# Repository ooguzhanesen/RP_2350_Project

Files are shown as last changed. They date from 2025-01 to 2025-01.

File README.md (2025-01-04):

# RP2350 PALS OKUMA VE GONERME KARTI
## KART ÖZELLİKLERİ 
- RP2350 mikrodenetleyici
- MG2608 GSM Modülü
- Ds3231 RTC
- RS485
- 2 adet optoizalatörlü Pals okuma girişi
- Adc okuma girişi
- Type c girişi
- 7-28 to 5v voltaj girişi
- 5v multiplexer 

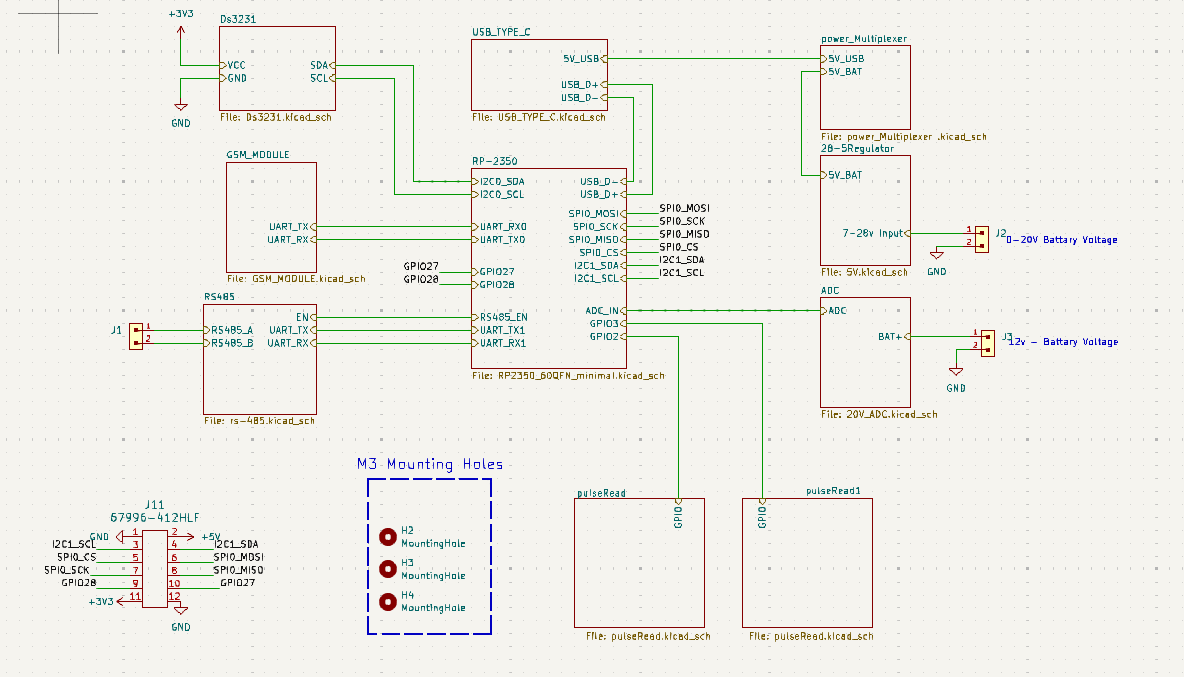
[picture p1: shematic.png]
proje şematik


## PCB TASARIMI
PCB kiCad üzerinden 4 kartlı olacak şekilde tasarlanmıştır. 
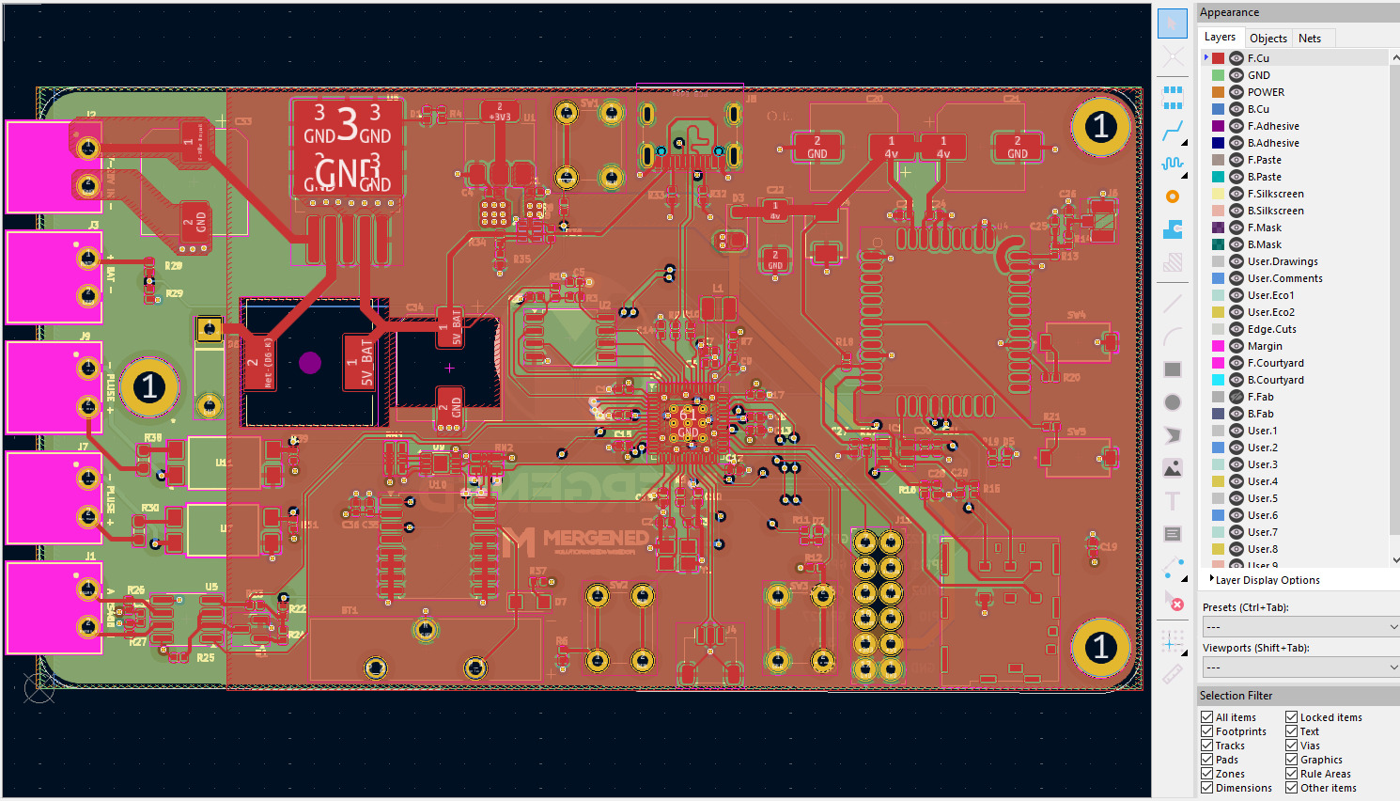
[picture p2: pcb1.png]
pcb Çizim


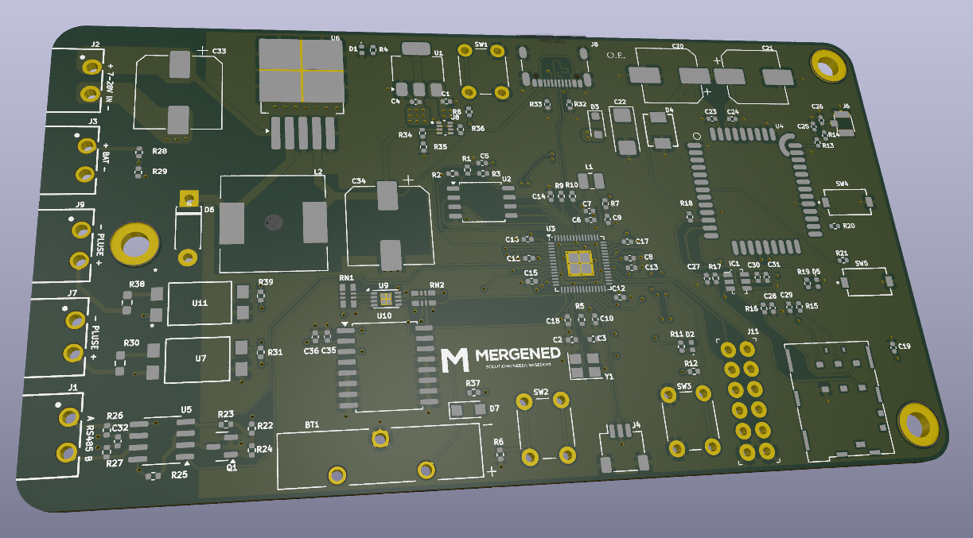
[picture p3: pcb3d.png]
pcb 3D


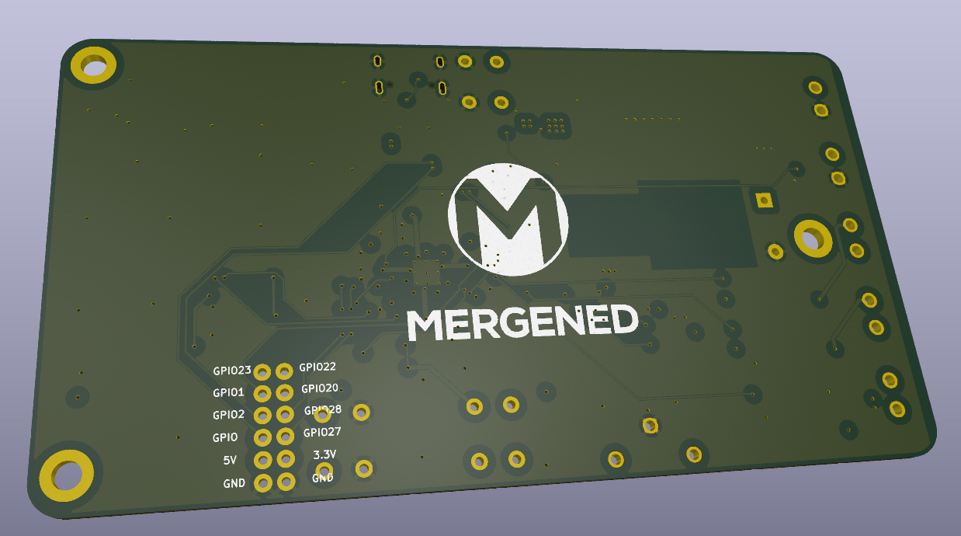
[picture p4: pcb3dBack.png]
PCB 3D BACKSIDE


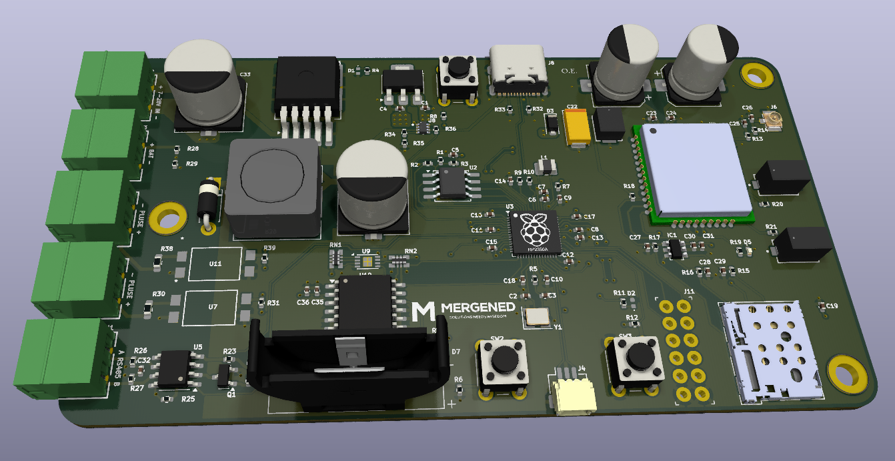
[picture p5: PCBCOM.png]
PCB COM


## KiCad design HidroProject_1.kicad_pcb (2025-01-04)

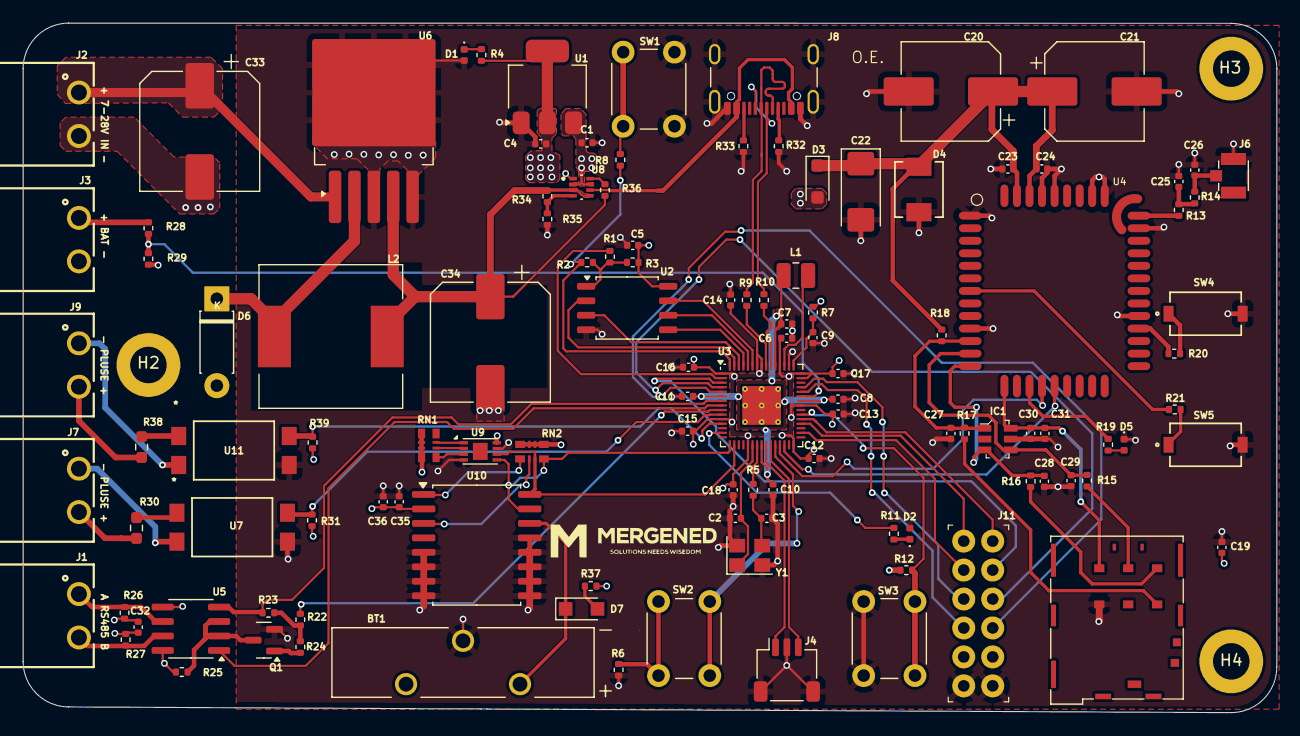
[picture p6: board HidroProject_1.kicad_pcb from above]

Board: 4 copper layers, 110.0 x 60.5 mm, 119 parts (0 on the bottom side), 92 nets.

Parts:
BT1: 1074; BAT_1074
C1, C4, C19: 10u; C_0402_1005Metric
C2, C3: 15p; C_0402_1005Metric
C5, C8, C11, C12, C13, C14, C15, C16, C17, C18: 100n; C_0402_1005Metric
C6, C7, C9, C10: 4.7u; C_0402_1005Metric
C20: 100uF; CP_Elec_8x10.5
C21: 470uF; CP_Elec_8x10.5
C22: C_Small; CP_EIA-6032-15_Kemet-U
C23: 0.1uF; C_0402_1005Metric
C24, C27, C28, C29, C30: 33pF; C_0402_1005Metric
C25, C26: 10pF; C_0402_1005Metric
C31: 1uF; C_0402_1005Metric
C32: 100nF; C_0402_1005Metric
C33: 680uF; CP_Elec_10x10
C34: 220uF; CP_Elec_10x10
C35: 0.1u; C_0402_1005Metric
C36: 1u; C_0402_1005Metric
D1, D2: LG_L29K-G2J1-24-Z; D_0402_1005Metric
D3: D; D_SOD-123F
D4: D_Zener; SMB-2_4P60X3P95_ONS
D5: LED; LED_0402_1005Metric
D6: 1N5824; D_DO-41_SOD81_P7.62mm_Horizontal
D7: 1N4148; Nexperia_CFP3_SOD-123W
H2, H3, H4: MountingHole; MountingHole_3.2mm_M3_DIN965_Pad
IC1: DALC208SC6; SOT23-6L
J1, J2, J3, J7, J9: 691322310002
J4: SM03B-SRSS-TB; JST_SH_SM03B-SRSS-TB_1x03-1MP_P1.00mm_Horizontal
J5: JAE_SIM_Card_SF72S006
J6: U.FL-R-SMT-1_10_; HRS_U.FL-R-SMT-1_10_
J8: USB_C_Receptacle_USB2.0_16P; USB_C_Receptacle_GCT_USB4105-xx-A_16P_TopMnt_Horizontal
J11: 67996-412HLF; PinHeader_6x2_P2.54mm_Vertical
L1: 3.3u; L_1008_2520Metric
L2: 33uH; L_12x12mm_H8mm
Q1: BSN20; SOT-23
R1, R3: DNF; R_0402_1005Metric
R2, R13, R14, R22, R23: 0R; R_0402_1005Metric
R4, R5, R6, R8, R11: 1k; R_0402_1005Metric
R7: 33; R_0402_1005Metric
R9, R10: 27; R_0402_1005Metric
R12, R31, R34, R39: 10k; R_0402_1005Metric
R15, R16, R17: 22R; R_0402_1005Metric
R18: 15K; R_0402_1005Metric
R19, R20, R21, R29: 1K; R_0402_1005Metric
R24, R25, R26, R27: 10K; R_0402_1005Metric
R28: 5K; R_0402_1005Metric
R30, R38: R; R_0603_1608Metric_Pad0.98x0.95mm_HandSolder
R32, R33: 5k1; R_0402_1005Metric
R35: 3k; R_0402_1005Metric
R36: 4.7k; R_0402_1005Metric
R37: 220; R_0402_1005Metric
RN1, RN2: EXB28V472JX; C_ARRAY_EXB28V_PAN
SW1, SW2, SW3: SW_Push; SW_PUSH_6mm_H5mm
SW4, SW5: BTN_DEACTIVE; SW_PTS636_CNK
U1: NCP1117-3.3_SOT223; SOT-223-3_TabPin2
U2: W25Q128JVS; SOIC-8_5.23x5.23mm_P1.27mm
U3: RP2350_60QFN; QFN-60-1EP_7x7mm_P0.4mm_EP3.4x3.4mm_ThermalVias
U4: MG2608
U5: Max3075EESA; SOIC-8_3.9x4.9mm_P1.27mm
U6: LM2596S-5; TO-263-5_TabPin3
U7, U11: EL8171S1TU-G; EL8171-S1-TU_EVE
U8: TPS2117DRLR; SOTFL50P160X60-8N
U9: AT24CS01-MAHM; DFN-8-1EP_3x2mm_P0.5mm_EP1.3x1.5mm
U10: DS3231M; SOIC-16W_7.5x10.3mm_P1.27mm
Y1: ABM8-272-T3; Crystal_SMD_3225-4Pin_3.2x2.5mm

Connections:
32K: RN2.1, U10.1 (32KHZ)
+1V1: C7.1, C8.1, C10.1, C11.1, L1.1, U3.6 (DVDD), U3.23 (DVDD), U3.39 (DVDD), U3.50 (VREG_FB)
+3V3: C4.1, C5.1, C6.1, C12.1, C13.1, C14.1, C15.1, C16.1, C17.1, C18.1, C19.1, C32.1, C35.1, C36.1, J11.11, R3.1, R4.2, R7.1, R12.1, R25.1, R26.1, R31.1, R37.1, R39.1, RN1.5, RN1.6, RN1.7, RN1.8, RN2.5, RN2.6, RN2.7, RN2.8, U1.2 (VO), U2.8 (VCC), U3.1 (IOVDD), U3.11 (IOVDD), U3.20 (IOVDD), U3.30 (IOVDD), U3.38 (IOVDD), U3.44 (ADC_AVDD), U3.45 (IOVDD), U3.49 (VREG_VIN), U3.53 (USB_OTP_VDD), U3.54 (QSPI_IOVDD), U5.8 (VCC), U9.8 (VCC), U10.2 (VCC)
+5V: C1.1, D3.2 (A), J11.2, U1.3 (VI), U8.2 (VOUT), U8.7 (VOUT)
/28-5Regulator/5V_BAT: C34.1, L2.1, R34.1, R36.1, U6.4 (FB), U8.3 (VIN1), U8.5 (MODE)
/28-5Regulator/7-28v Input: C33.1, J2.1, U6.1 (VIN)
/ADC/ADC: R28.2, R29.1, U3.40 (GPIO26_ADC0)
/ADC/BAT+: J3.1, R28.1
/GPIO27: J11.10, U3.41 (GPIO27_ADC1)
/GPIO28: J11.9, U3.42 (GPIO28_ADC2)
/GSM_MODULE/4v: C20.1, C21.1, C22.1, C23.1, C24.1, D3.1 (K), D4.1 (K), R18.1, U4.42 (VBAT), U4.43 (VBAT)
/GSM_MODULE/Net_light: R19.1, U4.16 (NETL_LIGHT)
/GSM_MODULE/PWRKEY: R21.1, U4.7 (PWRKEY)
/GSM_MODULE/REST: R20.1, U4.26 (REST)
/GSM_MODULE/RF_ANT: R13.2, U4.35 (RF_ANT)
/GSM_MODULE/SIM_CLK: C28.1, IC1.3 (I/O_2), R16.2, U4.13 (SIM_CLK)
/GSM_MODULE/SIM_DATA: C27.1, IC1.1 (I/O_1), R17.2, R18.2, U4.11 (SIM_DATA)
/GSM_MODULE/SIM_RST: C29.1, IC1.4 (I/O_3), R15.2, U4.12 (SIM_RST)
/GSM_MODULE/SIM_VDD: C30.1, C31.1, IC1.6 (I/O_4), J5.C1 (VCC), U4.14 (SIM_VDD)
/GSM_MODULE/UART_RX: U3.27 (GPIO16), U4.17 (UART1_RXD)
/GSM_MODULE/UART_TX: U3.28 (GPIO17), U4.18 (UART1_TXD)
/I2C1_SCL: J11.3, U3.5 (GPIO3)
/I2C1_SDA: J11.4, U3.4 (GPIO2)
/RP-2350/1USB_D+: R9.2, U3.52 (USB_DP)
/RP-2350/1USB_D-: R10.2, U3.51 (USB_DM)
/RP-2350/FLASH_SS: R1.2, R2.2, R3.2, U2.1 (~CS)
/RP-2350/GPIO0: R1.1, U3.2 (GPIO0)
/RP-2350/GPIO2: R31.2, U3.10 (GPIO7), U7.4
/RP-2350/GPIO3: R39.2, U3.12 (GPIO8), U11.4
/RP-2350/QSPI_SCLK: U2.6 (CLK), U3.56 (QSPI_SCLK)
/RP-2350/QSPI_SD0: U2.5 (DI(IO0)), U3.57 (QSPI_SD0)
/RP-2350/QSPI_SD1: U2.2 (DO(IO1)), U3.59 (QSPI_SD1)
/RP-2350/QSPI_SD2: U2.3 (IO2), U3.58 (QSPI_SD2)
/RP-2350/QSPI_SD3: U2.7 (IO3), U3.55 (QSPI_SD3)
/RP-2350/QSPI_SS: R2.1, R8.1, U3.60 (QSPI_SS)
/RP-2350/RS485_EN: R22.1, U3.9 (GPIO6)
/RP-2350/RUN: SW2.2, U3.26 (RUN)
/RP-2350/SWCLK: J4.1, U3.24 (SWCLK)
/RP-2350/SWD: J4.3, U3.25 (SWD)
/RP-2350/UART_RX1: U3.8 (GPIO5), U5.1 (RO)
/RP-2350/UART_TX1: R23.1, U3.7 (GPIO4), U5.4 (DI)
/RP-2350/USB_D+: J8.A7 (D-), J8.B7 (D-), R9.1
/RP-2350/USB_D-: J8.A6 (D+), J8.B6 (D+), R10.1
/RP-2350/VREG_AVDD: C9.1, R7.2, U3.46 (VREG_AVDD)
/RP-2350/VREG_LX: L1.2, U3.48 (VREG_LX)
/RP-2350/XIN: C2.1, U3.21 (XIN), Y1.1
/RP-2350/XOUT: R5.1, U3.22 (XOUT)
/RP-2350/~USB_BOOT: R8.2, SW1.2
/RS485/RS485_A: J1.1, R26.2, U5.6 (A)
/RS485/RS485_B: J1.2, R27.1, U5.7 (B)
/SPI0_CS: J11.5, U3.3 (GPIO1)
/SPI0_MISO: J11.8, U3.32 (GPIO20)
/SPI0_MOSI: J11.6, U3.35 (GPIO23)
/SPI0_SCK: J11.7, U3.34 (GPIO22)
/USB_TYPE_C/5V_USB: J8.A4 (VBUS), J8.A9 (VBUS), J8.B4 (VBUS), J8.B9 (VBUS), U8.6 (VIN2)
GND: BT1.N, C1.2, C2.2, C3.2, C4.2, C5.2, C6.2, C7.2, C8.2, C9.2, C10.2, C11.2, C12.2, C13.2, C14.2, C15.2, C16.2, C17.2, C18.2, C19.2, C20.2, C21.2, C22.2, C23.2, C24.2, C25.2, C26.2, C27.2, C28.2, C29.2, C30.2, C31.2, C32.2, C33.2, C34.2, C35.2, C36.2, D1.2, D2.2, D4.2 (A), D5.1 (K), D6.2 (A), IC1.5 (REF_1), J2.2, J3.2, J4.2, J4.MP (MountPin), J5.C5 (GND), J6.1, J8.A1 (GND), J8.A12 (GND), J8.B1 (GND), J8.B12 (GND), J8.S1 (SHIELD), J11.1, J11.12, Q1.2 (S), R6.2, R27.2, R29.2, R32.2, R33.2, R35.2, SW1.1, SW3.1, SW4.2, SW5.2, U1.1 (GND), U2.4 (GND), U3.47 (VREG_PGND), U3.61 (GND), U4.1 (GND), U4.10 (GND), U4.27 (GND), U4.34 (GND), U4.36 (GND), U4.37 (GND), U4.40 (GND), U4.41 (GND), U5.5 (GND), U6.3 (GND), U6.5 (~ON/OFF), U7.3, U8.1 (GND), U9.4 (GND), U9.7 (WP), U10.5 (GND), U10.6 (GND), U10.7 (GND), U10.8 (GND), U10.9 (GND), U10.10 (GND), U10.11 (GND), U10.12 (GND), U10.13 (GND), U11.3, Y1.2, Y1.4
unnamed: C3.1, R5.2, Y1.3
unnamed: C25.1, R13.1, R14.2
unnamed: C26.1, J6.2, R14.1
unnamed: D1.1, R4.1
unnamed: D2.1, R11.1
unnamed: D5.2 (A), R19.2
unnamed: D6.1 (K), L2.2, U6.2 (OUT)
unnamed: D7.2 (A), R37.2
unnamed: BT1.P_1, D7.1 (K), U10.14 (VBAT)
unnamed: J5.C3 (CLK), R16.1
unnamed: J5.C7 (I/O), R17.1
unnamed: J5.C2 (RST), R15.1
unnamed: J7.1, U7.2
unnamed: J7.2, R30.1
unnamed: J8.A5 (CC1), R32.1
unnamed: J8.B5 (CC2), R33.1
unnamed: J9.1, U11.2
unnamed: J9.2, R38.1
unnamed: Q1.3 (D), R25.2, U5.2 (~RE), U5.3 (DE)
unnamed: Q1.1 (G), R24.2
unnamed: R6.1, SW2.1
unnamed: R20.2, SW4.1
unnamed: R21.2, SW5.1
unnamed: R22.2, R23.2, R24.1
unnamed: R30.2, U7.1
unnamed: R38.2, U11.1
unnamed: R11.2, U3.14 (GPIO10)
unnamed: R12.2, SW3.2, U3.36 (GPIO24)
unnamed: R34.2, R35.1, U8.4 (PR1)
unnamed: R36.2, U8.8 (ST)
unnamed: RN1.3, U9.1 (A0)
unnamed: RN1.2, U9.2 (A1)
unnamed: RN1.1, U9.3 (A2)
SCL: RN2.3, U3.17 (GPIO13), U9.6 (SCL), U10.16 (SCL)
SDA: RN2.4, U3.16 (GPIO12), U9.5 (SDA), U10.15 (SDA)
SQW: RN2.2, U10.3 (~INT/SQW)

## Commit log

2025-01-04 fist commit
    [20V_ADC.kicad_sch, 5V.kicad_sch, Ds3231.kicad_sch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]
2025-01-04 mahlas guncellendi
    [HidroProject.kicad_pcb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]
